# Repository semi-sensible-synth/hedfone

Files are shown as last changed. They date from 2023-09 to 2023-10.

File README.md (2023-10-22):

# hedfone eurorack module

_Simple stereo sum fixed panning headphone output in 2HP_

## Features

A 2HP headphone output with:

- Left and right mono inputs at eurorack levels (left+left, right+right, summed)
- First set of inputs panned hard left/right, second set are 'soft' left/right by ~6dB in the stereo field
- A 3.5mm TRS stereo output at line/headphone levels (0.4x gain, 5V -> 2.1 Vpp output)
- Dual audio op-amps per output channel to drive headphones
- Volume adjustment knob
- Internal pin header to take input from other modules (eg a mixer)

Intended to be used with 0HP attenuators if one of the summed inputs needs to be mixed/panned, or a 0HP passive mult if you need to put a mono signal into both channels.

## Design

For the headphone output, I used design similar to [this headphone amplifier](http://www.redcircuits.com/Page155.htm) using a dual op-amp (NE5532) per channel. The first op amp unit acts as a unity gain buffer, with a second non-inverting op amp in parallel to the output acting as voltage follower/buffer to allow it to drive more current. Other modules that use a similar technique include the [Befaco Out v3](https://www.befaco.org/out-v3/) headphone driver or [Forest Caver's Headphone Amp module](https://github.com/forestcaver/Analog-Voice/tree/master/AJH_Headphone_Amp).

The 3.5mm TRS stereo jack can be a [green Thonkiconn PJ366ST](https://www.thonk.co.uk/shop/green-stereo-thonkiconn-jacks-pj366st-x1/) or a [Tayda A-6115](https://www.taydaelectronics.com/3-5mm-stereo-enclosed-socket.html) bodged with a resistor wire.

## Version 1.1.2 - TODO
_(fixes for next revision)_

- Pot direction is reversed.
- Outer L/R pair are hard panned, inner pair are soft panned. This wasn't intentional, but actually makes sense (more like Nearness) - swap inner pair order and front panel to reflect that (so we have top to bottom L/L/R/R with the outer jacks hard panned)

## Version 1.1.1

Fix footprint for D1,D2 (SOD-523 -> SOD-323)

## Version 1.1

Made the second set of inputs 'soft' panned left and right by ~6dB.
Removed left->right normalling for mono (can't easily co-exist with the soft panning feature)

## Version 1.0

Initial release to production.

## License

[CERN-OHL-S-2.0](https://ohwr.org/cern_ohl_s_v2.txt) (*CERN Open Hardware License Version 2 - Strongly Reciprocal*), Andrew Perry, 2023.

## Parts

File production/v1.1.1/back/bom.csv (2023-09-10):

Designator | Footprint | Quantity | Value | LCSC Part #
C1, C10, C2, C5, C6, C7, C8, C9 | 0603 | 8 | 100n | C14663
C11, C12 | 0603 | 2 | 47p | C1671
C13, C14, C3, C4 | 1206 | 4 | 10u | C13585
D1, D2 | D_SOD-323 | 2 | 1N5819WS | C191023
J1 | 3.5mm_tip_switch_thonkiconn | 1 | IN_L1
J2 | 3.5mm_tip_switch_thonkiconn | 1 | IN_L2
J3 | 3.5mm_tip_switch_thonkiconn | 1 | IN_R1
J4 | 3.5mm_tip_switch_thonkiconn | 1 | IN_R2
J5 | 3.5mm_tip_switch_thonkiconn | 1 | OUT_LR
J6 | PinHeader_2x05_P2.54mm_Vertical | 1 | Eurorack Power
J7 | PinHeader_1x03_P2.54mm_Vertical | 1 | Conn_01x03_Male
J8 | PinHeader_1x02_P2.54mm_Vertical | 1 | Conn_01x02_Female
R1, R2, R5, R6 | 0603 | 4 | 100k | C25803
R10, R3, R4, R9 | 0603 | 4 | 10k | C25804
R11, R12, R13, R14 | 0603 | 4 | 47 | C23182
R15, R16 | 0603 | 2 | 200k | C25811
R7, R8 | 0603 | 2 | 43k | C23172
RV1 | Potentiometer_Alpha_RD902F-40-00D_Dual_Vertical | 1 | A100K
U1 | SOIC-8_3.9x4.9mm_P1.27mm | 1 | TL072 | C6961
U2, U3 | SOIC-8_3.9x4.9mm_P1.27mm | 2 | NE5532 | C7426

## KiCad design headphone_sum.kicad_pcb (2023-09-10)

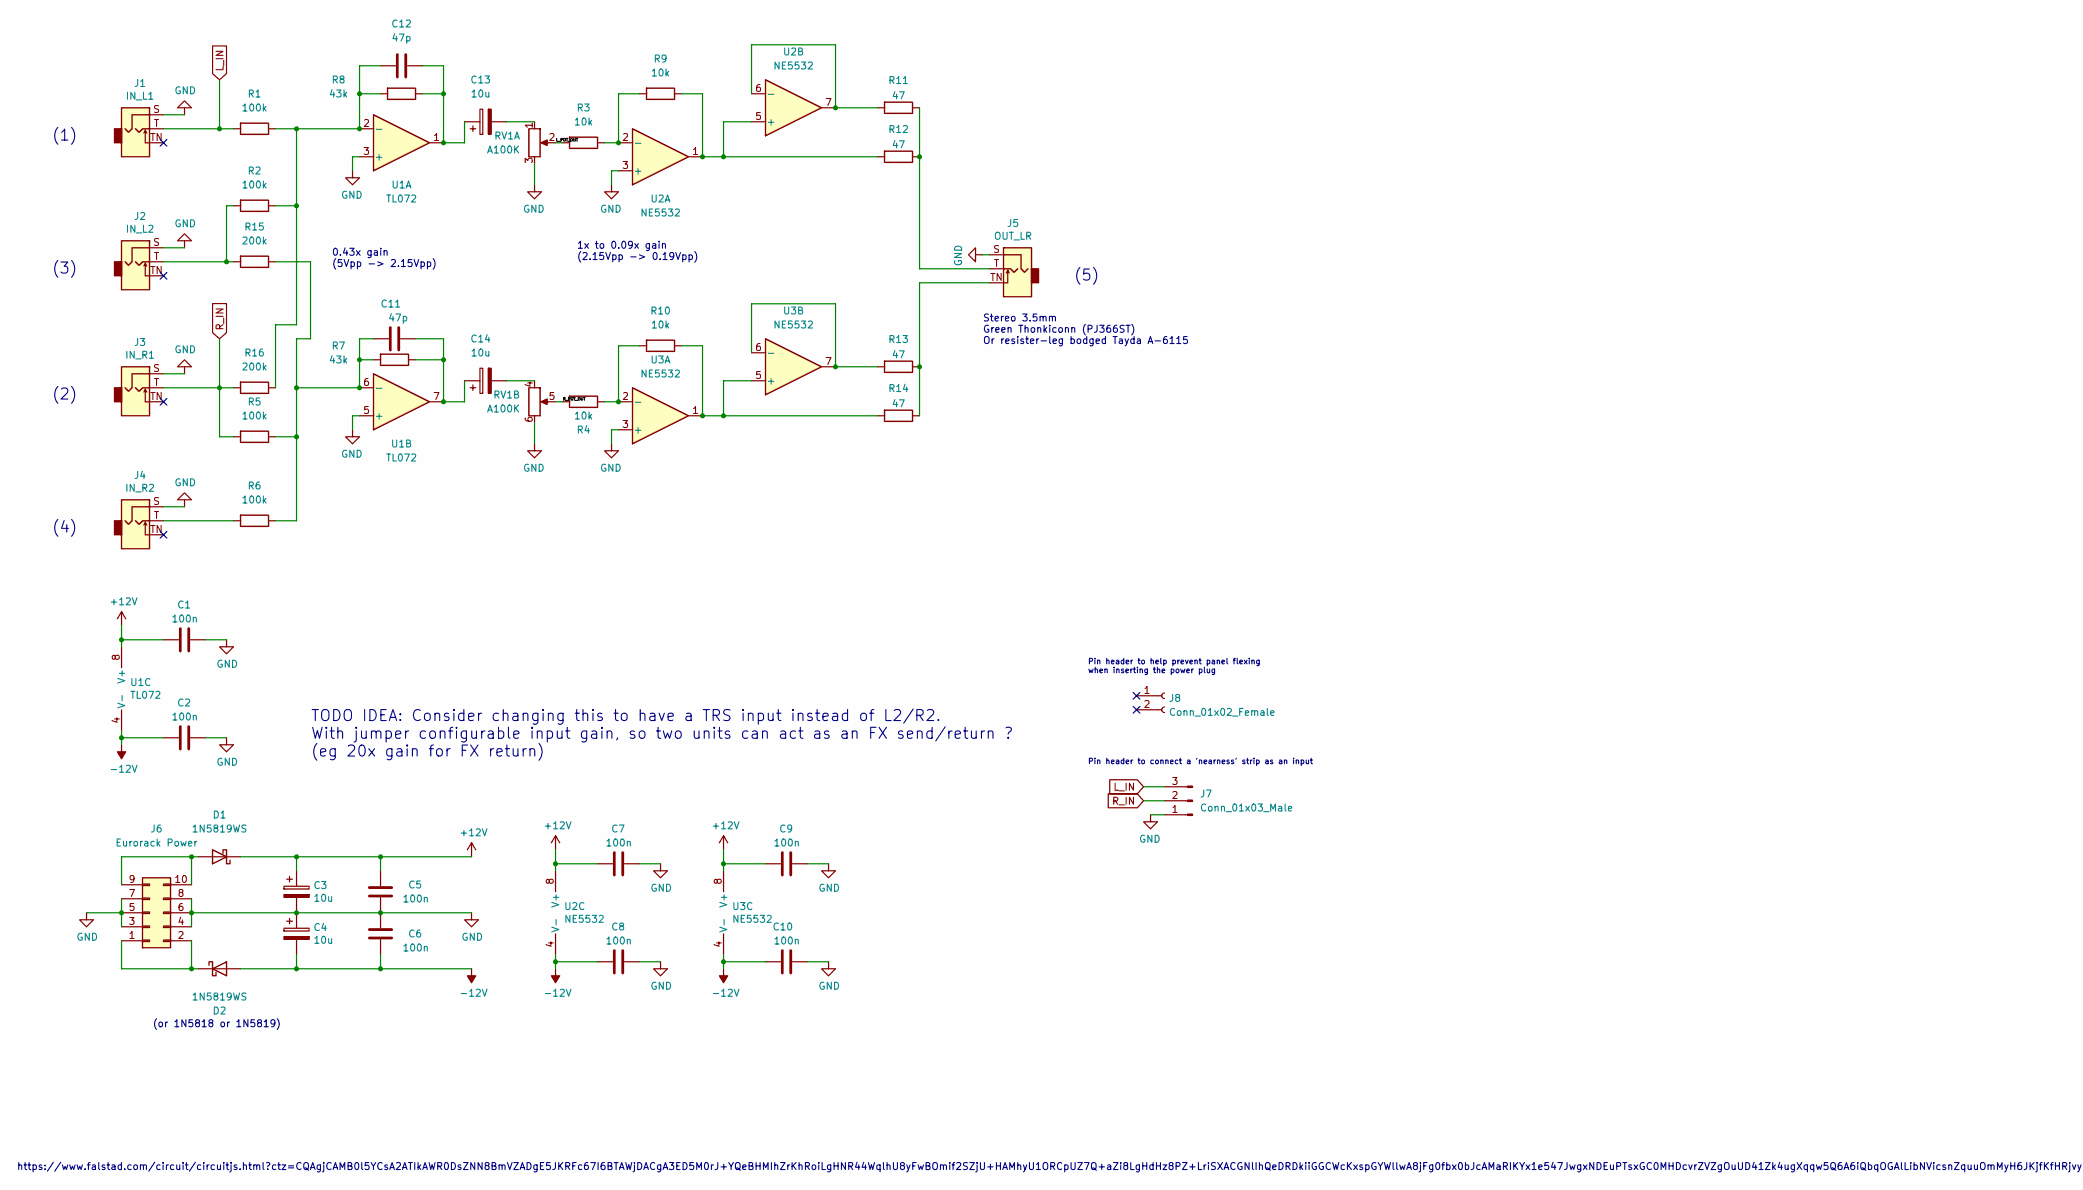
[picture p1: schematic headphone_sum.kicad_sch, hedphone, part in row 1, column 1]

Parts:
C1, C2, C5, C6, C7, C8, C9, C10: 100n; C_0603_1608Metric_Pad1.08x0.95mm_HandSolder; LCSC part number C14663
C3, C4, C13, C14: 10u; C_1206_3216Metric_Pad1.33x1.80mm_HandSolder; LCSC C13585
C11, C12: 47p; C_0603_1608Metric_Pad1.08x0.95mm_HandSolder; LCSC part number C1671
D1, D2: 1N5819WS; D_SOD-323; LCSC part number C191023
J1: IN_L1; 3.5mm_tip_switch_thonkiconn
J2: IN_L2; 3.5mm_tip_switch_thonkiconn
J3: IN_R1; 3.5mm_tip_switch_thonkiconn
J4: IN_R2; 3.5mm_tip_switch_thonkiconn
J5: OUT_LR; 3.5mm_tip_switch_thonkiconn
J6: Eurorack Power; PinHeader_2x05_P2.54mm_Vertical
J7: Conn_01x03_Male; PinHeader_1x03_P2.54mm_Vertical
J8: Conn_01x02_Female; PinHeader_1x02_P2.54mm_Vertical
R1, R2, R5, R6: 100k; R_0603_1608Metric_Pad0.98x0.95mm_HandSolder; LCSC part number C25803
R3, R4, R9, R10: 10k; R_0603_1608Metric_Pad0.98x0.95mm_HandSolder; LCSC part number C25804
R7, R8: 43k; R_0603_1608Metric_Pad0.98x0.95mm_HandSolder; LCSC part number C23172
R11, R12, R13, R14: 47; R_0603_1608Metric_Pad0.98x0.95mm_HandSolder; LCSC part number C23182
R15, R16: 200k; R_0603_1608Metric_Pad0.98x0.95mm_HandSolder; LCSC part number C25811
RV1: A100K; Potentiometer_Alpha_RD902F-40-00D_Dual_Vertical
U1: TL072; SOIC-8_3.9x4.9mm_P1.27mm; LCSC part number C6961
U2, U3: NE5532; SOIC-8_3.9x4.9mm_P1.27mm; LCSC part number C7426

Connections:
+12V: C1.1, C3.1, C5.2, C7.1, C9.1, D1.1 (K), U1.8 (V+), U2.8 (V+), U3.8 (V+)
-12V: C2.1, C4.2, C6.1, C8.1, C10.1, D2.2 (A), U1.4 (V-), U2.4 (V-), U3.4 (V-)
/L_POT_OUT: R3.2, RV1.2
/R_POT_OUT: R4.2, RV1.5
GND: C1.2, C2.2, C3.2, C4.1, C5.1, C6.2, C7.2, C8.2, C9.2, C10.2, J1.S, J2.S, J3.S, J4.S, J5.S, J6.3, J6.4, J6.5, J6.6, J6.7, J6.8, J7.1, RV1.3, RV1.6, U1.3 (+), U1.5 (+), U2.3 (+), U3.3 (+)
L_IN: J1.T, J7.3, R1.2
unnamed: C11.2, C14.1, R7.1, U1.7
unnamed: C12.2, C13.1, R8.1, U1.1
unnamed: C13.2, RV1.1
unnamed: C14.2, RV1.4
unnamed: D1.2 (A), J6.9, J6.10
unnamed: D2.1 (K), J6.1, J6.2
unnamed: J2.T, R2.2, R15.2
unnamed: J4.T, R6.2
unnamed: J5.T, R11.1, R12.1
unnamed: J5.TN, R13.1, R14.1
unnamed: C12.1, R1.1, R2.1, R8.2, R16.1, U1.2 (-)
unnamed: C11.1, R5.1, R6.1, R7.2, R15.1, U1.6 (-)
unnamed: R3.1, R9.2, U2.2 (-)
unnamed: R9.1, R12.2, U2.1, U2.5 (+)
unnamed: R11.2, U2.6 (-), U2.7
unnamed: R4.1, R10.2, U3.2 (-)
unnamed: R10.1, R14.2, U3.1, U3.5 (+)
unnamed: R13.2, U3.6 (-), U3.7
R_IN: J3.T, J7.2, R5.2, R16.2

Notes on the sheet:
(3)
(4)
Stereo 3.5mm Green Thonkiconn (PJ366ST) Or resister-leg bodged Tayda A-6115
Pin header to connect a 'nearness' strip as an input
(1)
TODO IDEA: Consider changing this to have a TRS input instead of L2/R2. With jumper configurable input gain, so two units can act as an FX send/return ? (eg 20x gain for FX return)
0.43x gain (5Vpp -> 2.15Vpp)
(or 1N5818 or 1N5819)
(2)
(5)
https://www.falstad.com/circuit/circuitjs.html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…
1x to 0.09x gain (2.15Vpp -> 0.19Vpp)
Pin header to help prevent panel flexing when inserting the power plug

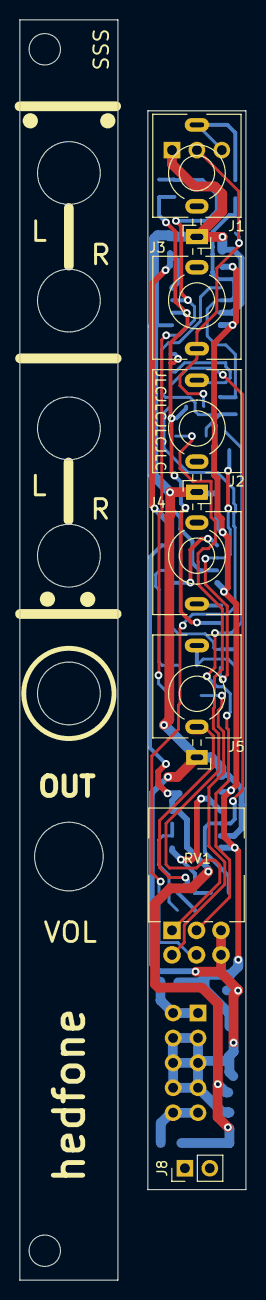
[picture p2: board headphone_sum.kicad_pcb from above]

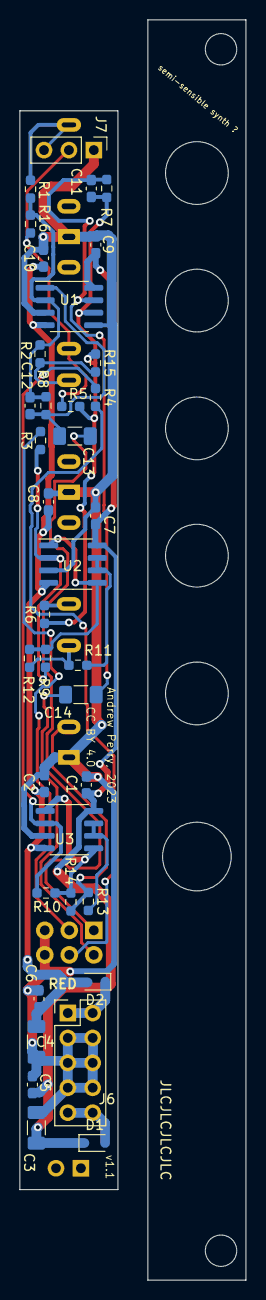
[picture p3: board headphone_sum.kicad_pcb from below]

Board: 2 copper layers, 10.0 x 110.0 mm, 46 parts (37 on the bottom side), 25 nets.

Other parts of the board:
M3 Screw: MountingHole_3.2mm_M3
M3 screw: locked; MountingHole_3.2mm_M3

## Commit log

2023-08-06 Initial commit, schematic and PCB layout
    [headphone_sum.kicad_pcb, headphone_sum.kicad_sch, headphone_sum.sch]
2023-08-06 Generate gerbers and BOM for front and back
    [bom.csv, designators.csv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]
2023-08-29 Remove duplicate front/back file, old KiCad files.
    [headphone_sum.kicad_pcb, headphone_sum.kicad_sch, headphone_sum.sch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]
2023-08-29 Generate gerbers, production files for v1.1
    [bom.csv, designators.csv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]
2023-09-09 BOM and position file fixes
    [bom.csv, headphone_sum.kicad_sch, positions.csv]
2023-09-10 v1.1.1, fix some LCSC part numbers, fix D1,D2 footprint
    [bom.csv, designators.csv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]

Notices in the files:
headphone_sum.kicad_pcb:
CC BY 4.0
